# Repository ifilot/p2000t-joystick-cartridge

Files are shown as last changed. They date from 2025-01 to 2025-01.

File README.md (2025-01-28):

# P2000T Joystick Cartridge for SLOT2






This cartridge enables the use of Atari 2600-style joysticks with the P2000T by
emulating keyboard inputs. It uses an EEPROM and a few logic chips to translate
joystick button presses into keystrokes, seamlessly integrating with the
P2000T's keyboard polling process.

> [!TIP]
> Download a copy of the EEPROM binary [via this link](https://github.com/ifilot/p2000t-joystick-cartridge/releases/download/nightly/joystick_eeprom.bin).

## PCB

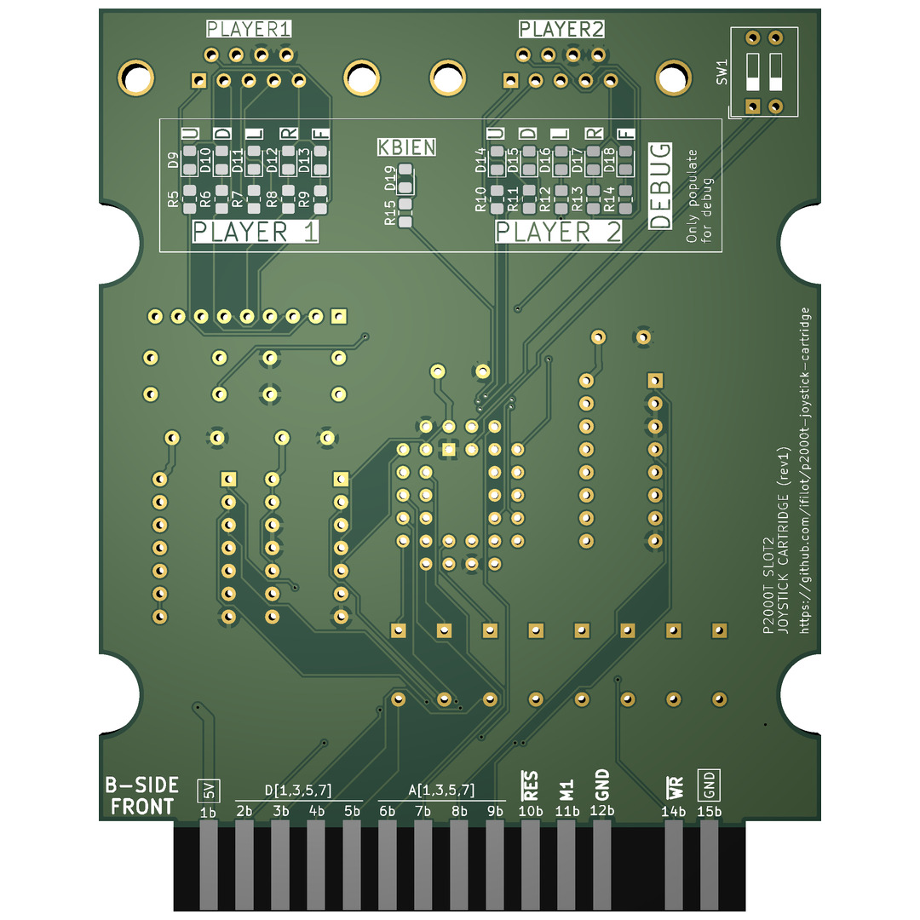
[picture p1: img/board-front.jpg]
PCB-front


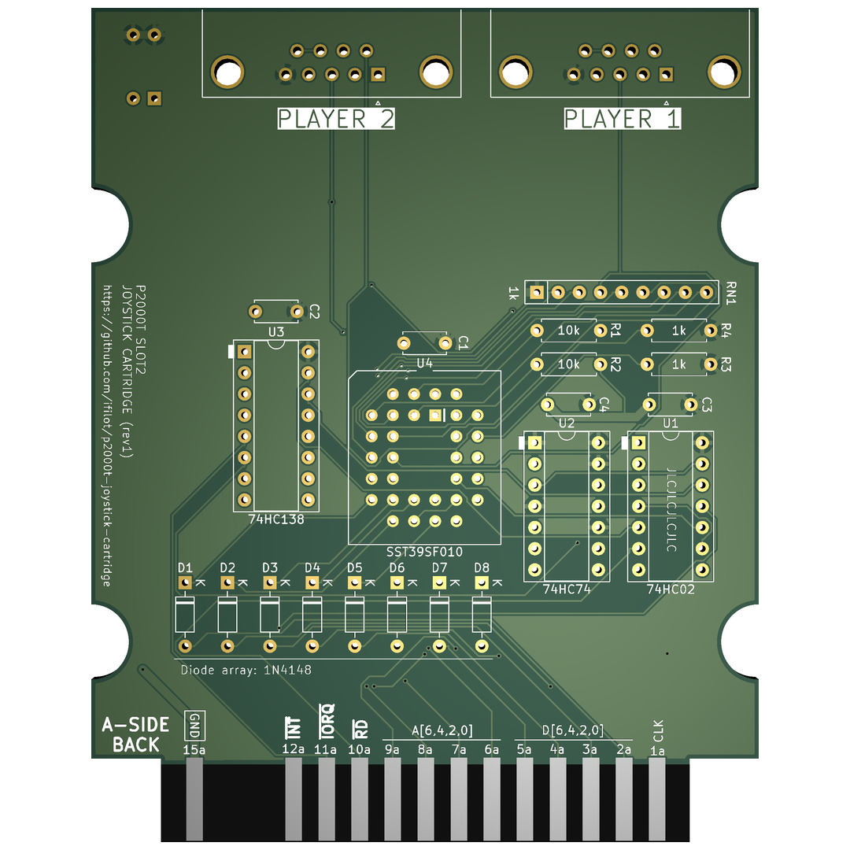
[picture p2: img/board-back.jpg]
PCB-back


## Working

The P2000T features a matrix keyboard design, where each key is positioned at the intersection of a specific row and column. The rows are connected to the address pins, while the columns are connected to the data pins. The keyboard matrix consists of 10 rows and 8 columns.

## Keyboard Polling Process

To poll the keyboard, the P2000T employs a two-step process:

1. **Initialize Rows**: The P2000T writes a `1` to the `BIT6` position of I/O
   port `0x10`, which ties all rows to ground (GND).
2. **Detect Key Presses**: The P2000T then reads from I/O port `0x00`. If at
   least one key is pressed, the read value will differ from `0xFF`.

If a key press is detected, the P2000T proceeds with an additional step:

3. **Detect specific key**: Each row is sequentially pulled down by reading from
   I/O ports `0x00` to `0x0A`. A zero-bit received during any of these read
   operations indicates the presence of a key press. The corresponding key is
   mapped to a specific keystroke based on its position in the matrix.

The described process is emulated using a single EEPROM and a few logic chips.
The EEPROM’s address pins are connected to both the joystick buttons and the
lower address bus used by the P2000T during the keyboard polling process. To
detect the polling of the lines, a 74HC138 decoder is used. This decoder latches
the D6 pin to capture the first phase of the keyboard polling process. During
this phase, if any joystick button is pressed, the EEPROM generates the same
output as if a key on the keyboard had been pressed. In the second phase, the
EEPROM continues the emulation process. However, it now produces the output
precisely when the corresponding row in the keyboard matrix is pulled low.

The use of an EEPROM makes this process fully programmable, allowing the user to
create any desired joystick-to-keyboard mapping. With 10 joystick buttons (5 per
joystick across 2 ports), only 32 KiB of EEPROM memory is required to store the
mappings. Since even the smallest SST39SF0x0-type EEPROM has a capacity of 128
KiB, a single chip can accommodate up to four different joystick/keyboard
mappings. To enable users to select their preferred mapping, a DIP switch is
included, allowing easy switching between the stored configurations.

### Schematic

[Download schematic](pcb/p2000t-joystick-slot2-eeprom/p2000t-joystick-slot2-eeprom.pdf)
PCB schematic

## Programming the EEPROM

To generate the data for the EEPROM, you can use [this
script](scripts/eeprom.py). The data can be written to the EEPROM using, for
example, [this hardware solution](https://github.com/ifilot/pico-sst39sf0x0-programmer).

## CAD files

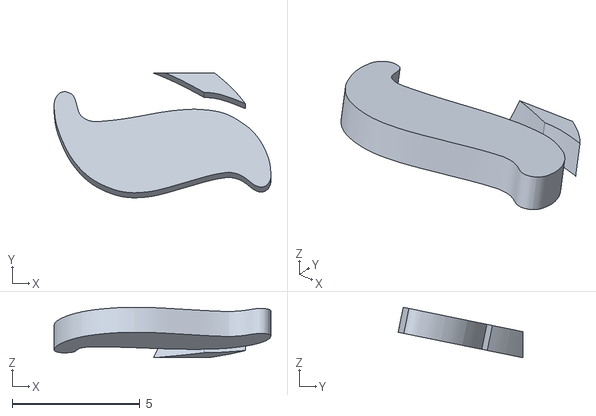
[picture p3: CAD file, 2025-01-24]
case/p2000t-joystick-cartridge-top-label.stl
8.51 x 4.90 x 1.98

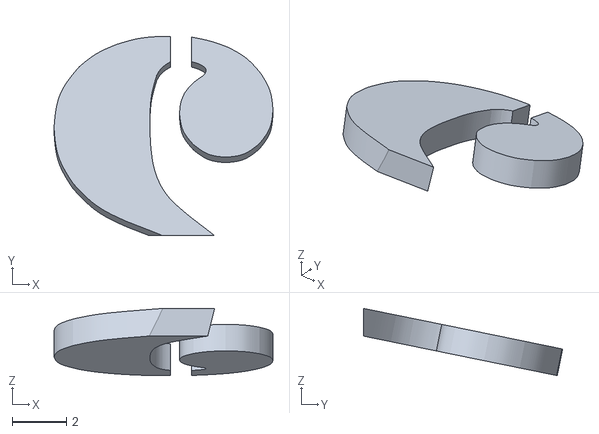
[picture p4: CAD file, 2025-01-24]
case/p2000t-joystick-cartridge-bottom-label.stl
8.08 x 7.35 x 2.48

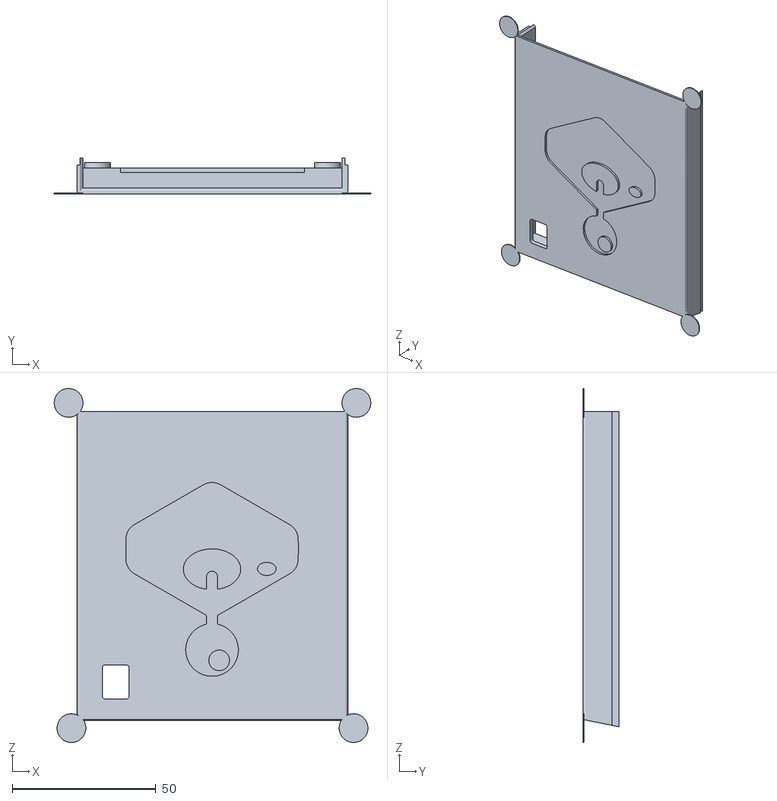
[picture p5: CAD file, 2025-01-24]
case/p2000t-joystick-cartridge-top.stl
110.0 x 12.5 x 123.0

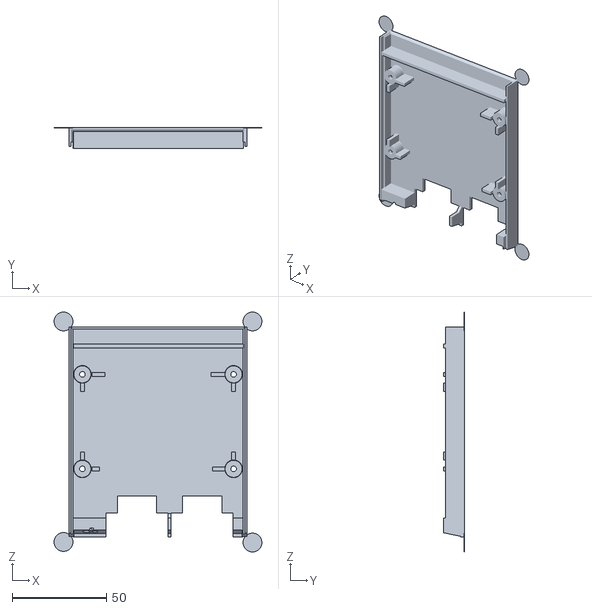
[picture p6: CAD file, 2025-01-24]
case/p2000t-joystick-cartridge-bottom.stl
110.0 x 11.0 x 127.0

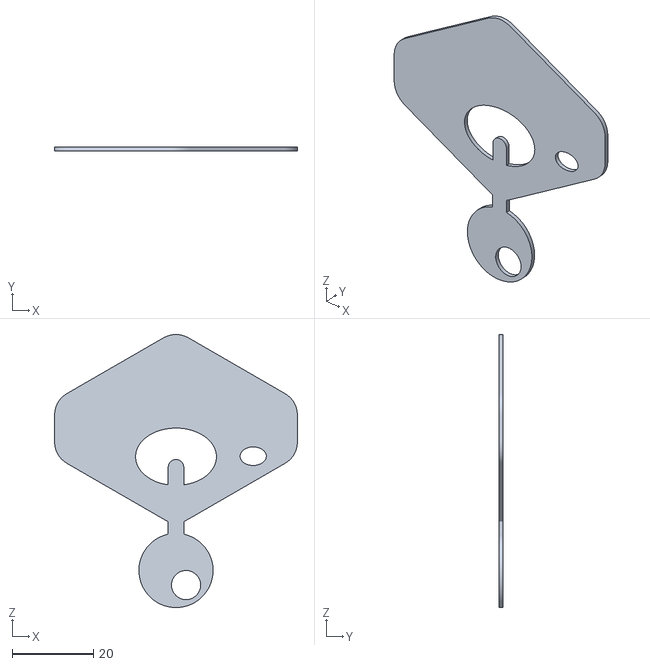
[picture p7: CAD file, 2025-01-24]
case/p2000t-joystick-cartridge-top-icon.stl
59.9 x 1.00 x 67.3

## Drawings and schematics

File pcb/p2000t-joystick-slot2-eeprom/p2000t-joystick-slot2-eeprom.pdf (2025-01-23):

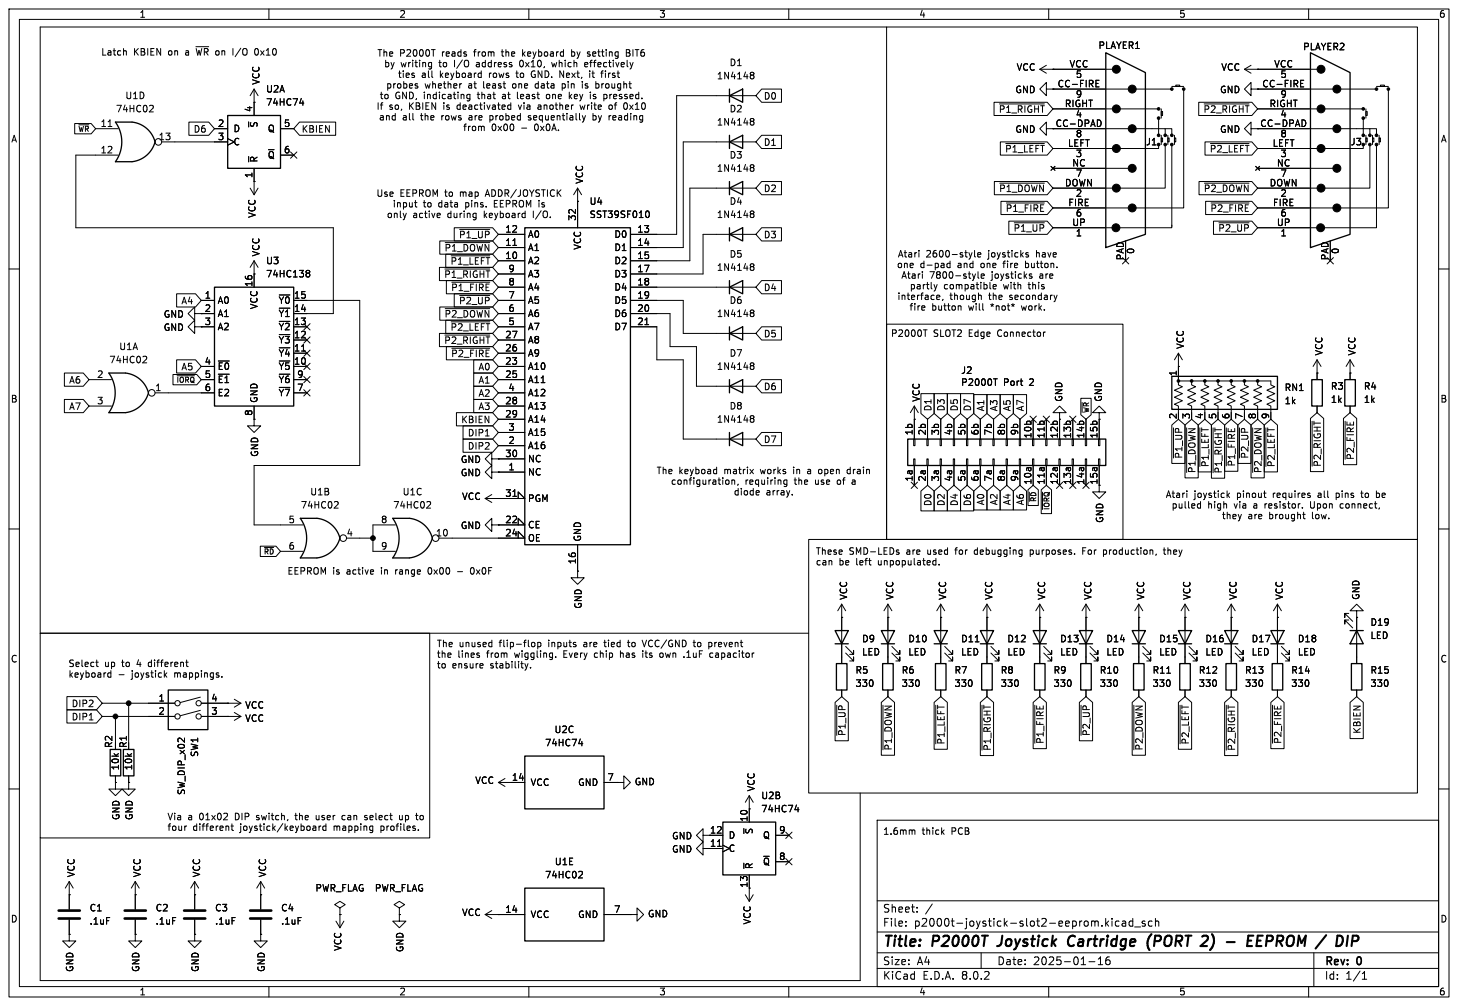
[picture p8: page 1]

input to data pins. EEPROM is only active during keyboard I/O. The P2000T reads from the keyboard by setting BIT6
by writing to I/O address 0x10, which effectively
ties all keyboard rows to GND. Next, it first probes whether at least one data pin is brought

~{P1_RIGHT} EEPROM is active in range 0x00 - 0x0F

8 ~{Y6}9 GND GND GND VCC

File: p2000t-joystick-slot2-eeprom.kicad_sch Sheet: /
Id: 1/1 Title: P2000T Joystick Cartridge (PORT 2) - EEPROM / DIP

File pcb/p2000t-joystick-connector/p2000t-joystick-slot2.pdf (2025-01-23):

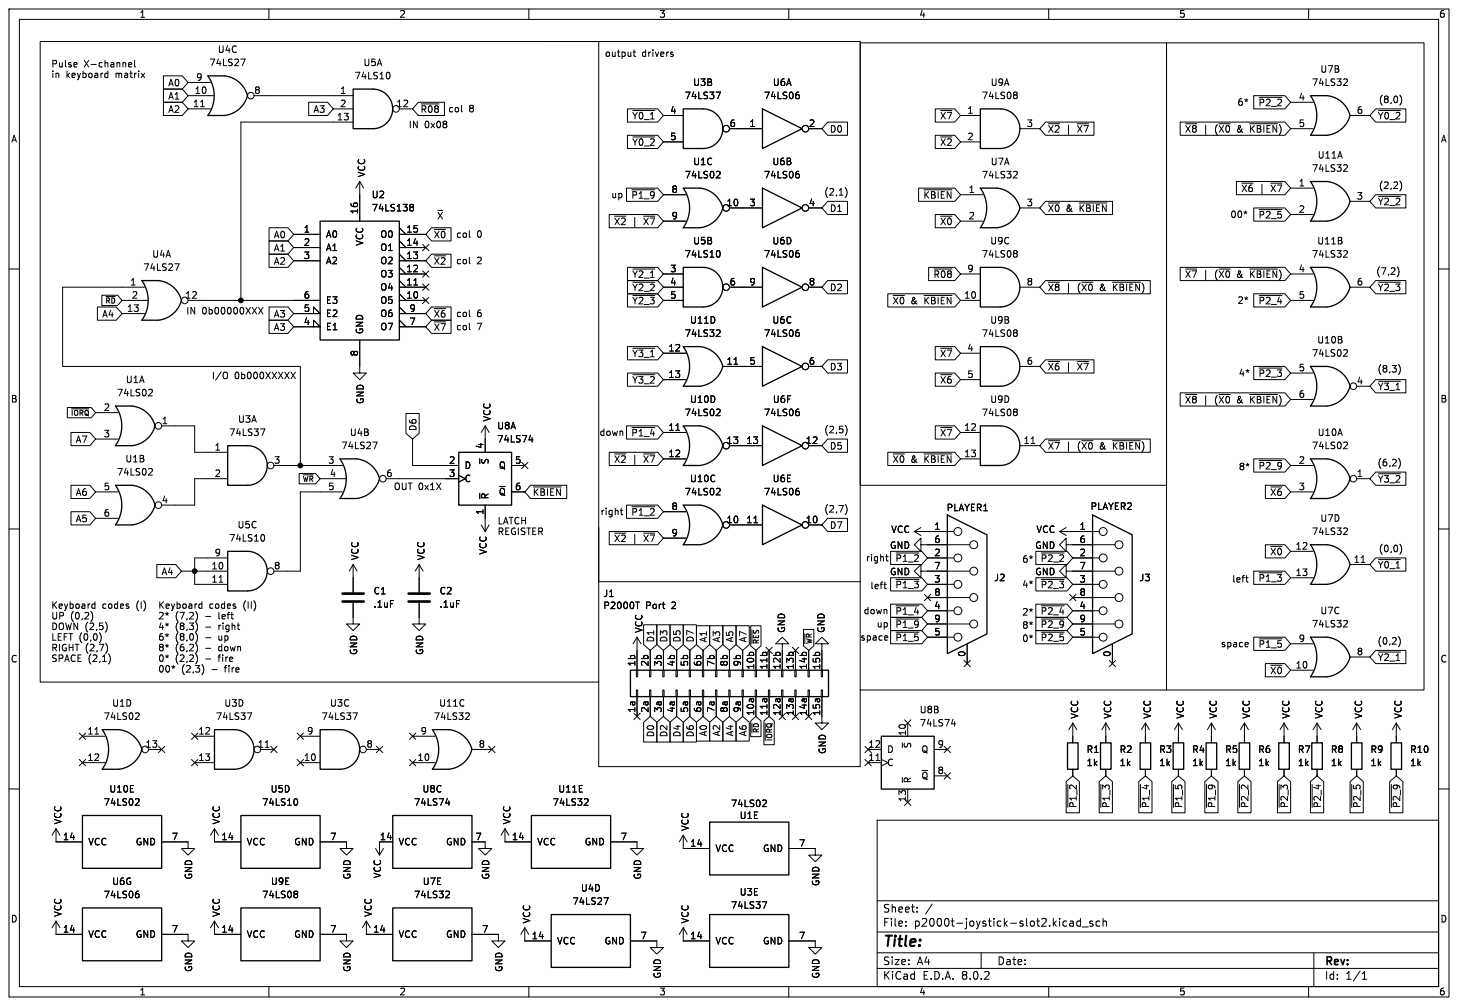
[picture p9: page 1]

Keyboard codes (I) UP (0,2) DOWN (2,5) LEFT (0,0) RIGHT (2,7) SPACE (2,1)

Keyboard codes (II) 2* (7,2) - left 4* (8,3) - right 6* (8,0) - up

Id: 1/1 Title: File: p2000t-joystick-slot2.kicad_sch Sheet: /

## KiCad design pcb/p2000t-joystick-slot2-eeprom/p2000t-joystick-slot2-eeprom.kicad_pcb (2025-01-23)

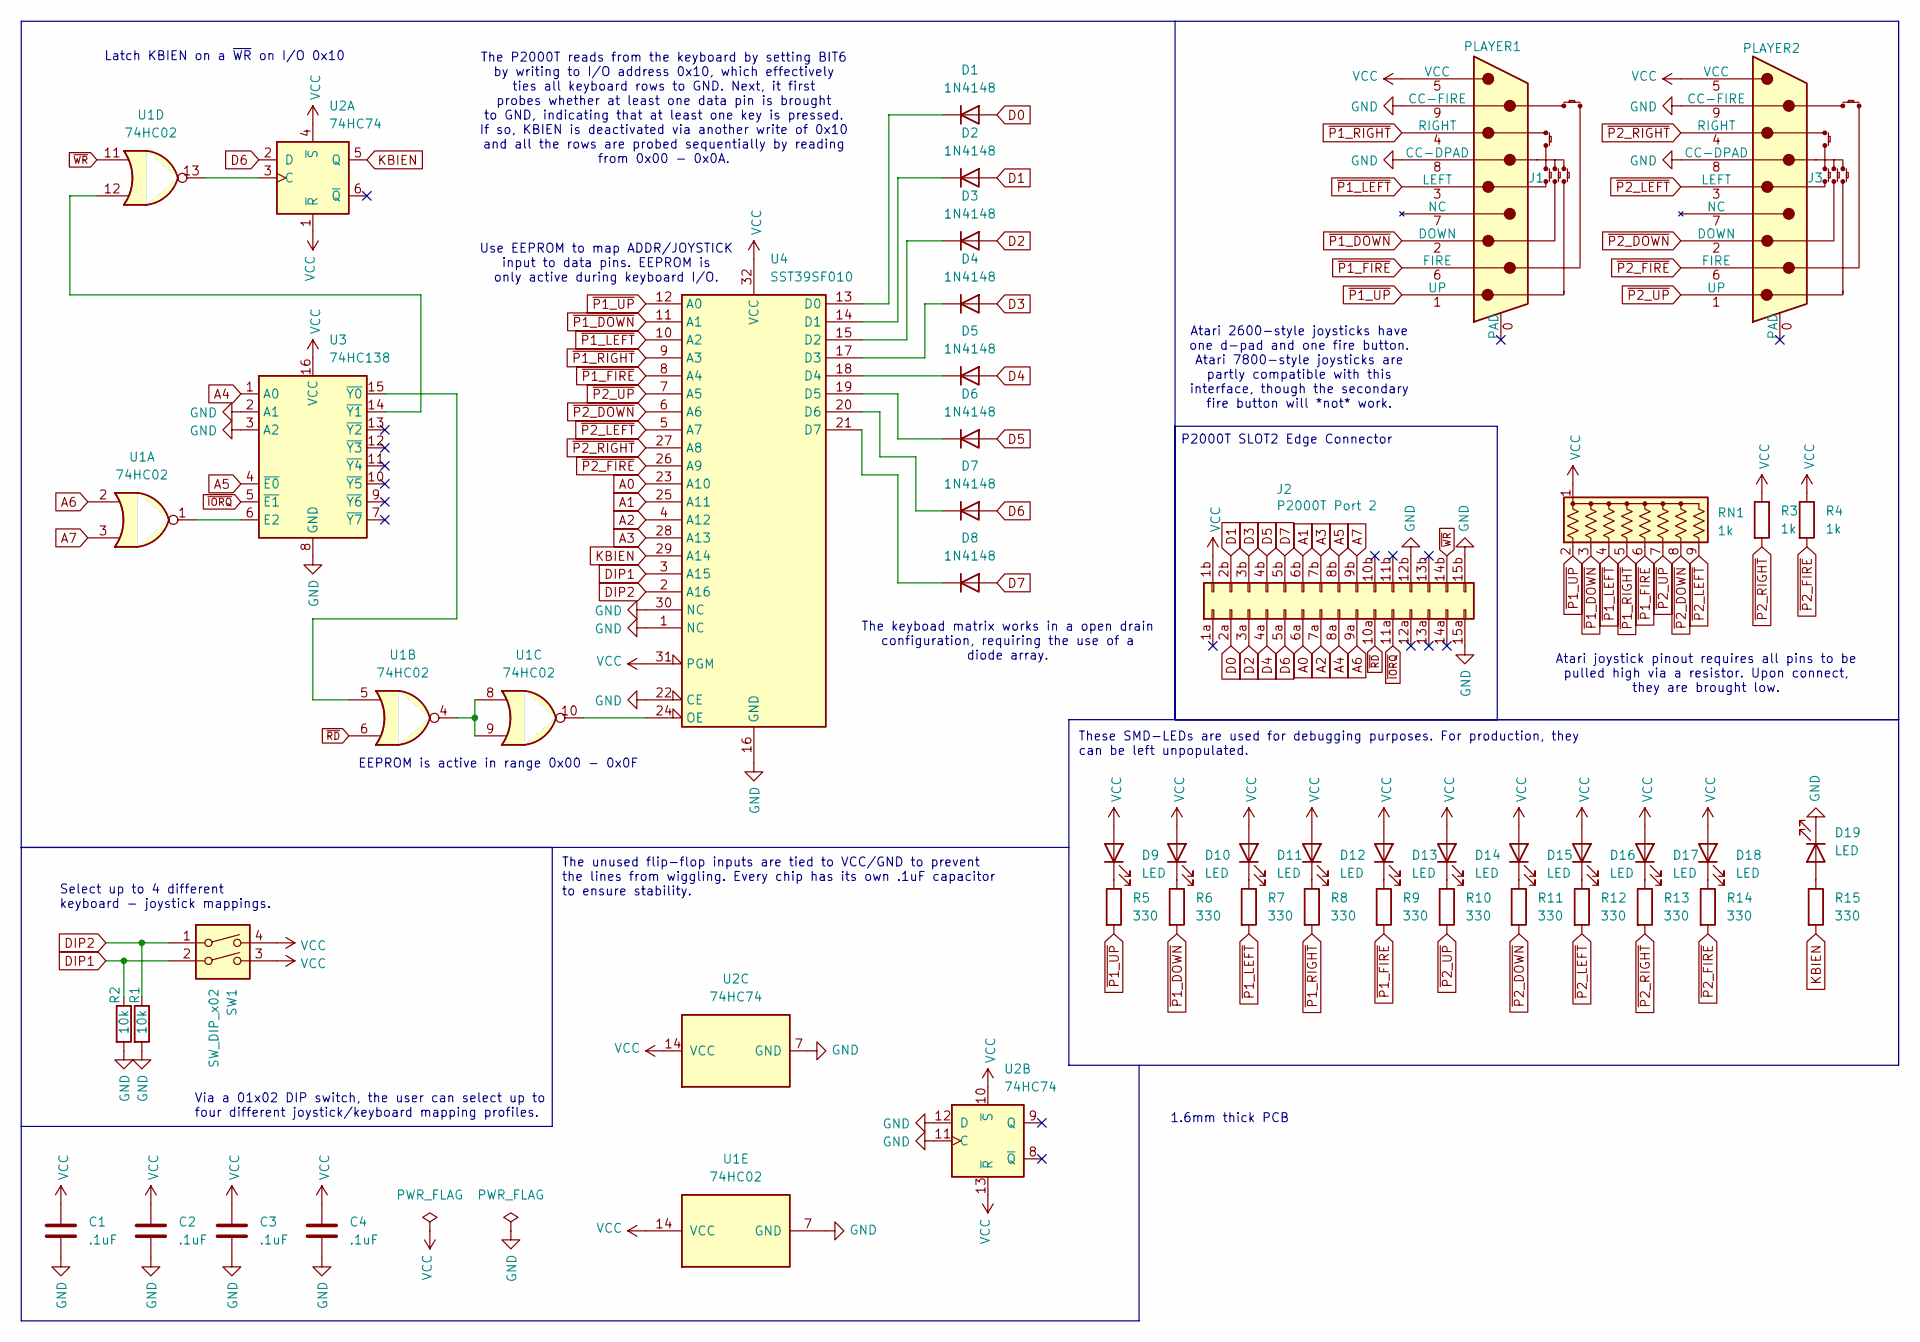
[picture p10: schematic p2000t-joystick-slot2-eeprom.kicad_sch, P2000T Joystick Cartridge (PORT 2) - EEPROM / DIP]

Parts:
C1, C2, C3, C4: .1uF; C_Disc_D5.0mm_W2.5mm_P5.00mm
D1, D2, D3, D4, D5, D6, D7, D8: 1N4148; D_DO-35_SOD27_P7.62mm_Horizontal
D9, D10, D11, D12, D13, D14, D15, D16, D17, D18, D19: LED; LED_0805_2012Metric_Pad1.15x1.40mm_HandSolder
J1: PLAYER1; DSUB-9_Male_Horizontal_P2.77x2.84mm_EdgePinOffset4.94mm_Hou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
J2: P2000T Port 2; p2000t_cartridge_edge
J3: PLAYER2; DSUB-9_Male_Horizontal_P2.77x2.84mm_EdgePinOffset4.94mm_Hou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
R1, R2: 10k; R_Axial_DIN0207_L6.3mm_D2.5mm_P7.62mm_Horizontal
R3, R4: 1k; R_Axial_DIN0207_L6.3mm_D2.5mm_P7.62mm_Horizontal
R5, R6, R7, R8, R9, R10, R11, R12, R13, R14, R15: 330; R_0805_2012Metric_Pad1.20x1.40mm_HandSolder
RN1: 1k; R_Array_SIP9
SW1: SW_DIP_x02; SW_DIP_SPSTx02_Slide_9.78x7.26mm_W7.62mm_P2.54mm
U1: 74HC02; DIP-14_W7.62mm_Socket
U2: 74HC74; DIP-14_W7.62mm_Socket
U3: 74HC138; DIP-16_W7.62mm_Socket
U4: SST39SF010; PLCC-32_THT-Socket

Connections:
A0: J2.6a, U4.23 (A10)
A1: J2.6b, U4.25 (A11)
A2: J2.7a, U4.4 (A12)
A3: J2.7b, U4.28 (A13)
A4: J2.8a, U3.1 (A0)
A5: J2.8b, U3.4 (~E0)
A6: J2.9a, U1.2
A7: J2.9b, U1.3
D0: D1.2 (A), J2.2a
D1: D2.2 (A), J2.2b
D2: D3.2 (A), J2.3a
D3: D4.2 (A), J2.3b
D4: D5.2 (A), J2.4a
D5: D6.2 (A), J2.4b
D6: D7.2 (A), J2.5a, U2.2 (D)
D7: D8.2 (A), J2.5b
DIP1: R2.1, SW1.2, U4.3 (A15)
DIP2: R1.1, SW1.1, U4.2 (A16)
GND: C1.2, C2.2, C3.2, C4.2, D19.1 (K), J1.8 (CC-DPAD), J1.9 (CC-FIRE), J2.12b, J2.15a, J2.15b, J3.8 (CC-DPAD), J3.9 (CC-FIRE), R1.2, R2.2, U1.7 (GND), U2.7 (GND), U2.11 (C), U2.12 (D), U3.2 (A1), U3.3 (A2), U3.8 (GND), U4.1 (NC), U4.16 (GND), U4.22 (CE), U4.30 (NC)
KBIEN: R15.2, U2.5 (Q), U4.29 (A14)
unnamed: D1.1 (K), U4.13 (D0)
unnamed: D2.1 (K), U4.14 (D1)
unnamed: D3.1 (K), U4.15 (D2)
unnamed: D4.1 (K), U4.17 (D3)
unnamed: D5.1 (K), U4.18 (D4)
unnamed: D6.1 (K), U4.19 (D5)
unnamed: D7.1 (K), U4.20 (D6)
unnamed: D8.1 (K), U4.21 (D7)
unnamed: D9.1 (K), R5.1
unnamed: D10.1 (K), R6.1
unnamed: D11.1 (K), R7.1
unnamed: D12.1 (K), R8.1
unnamed: D13.1 (K), R9.1
unnamed: D14.1 (K), R10.1
unnamed: D15.1 (K), R11.1
unnamed: D16.1 (K), R12.1
unnamed: D17.1 (K), R13.1
unnamed: D18.1 (K), R14.1
unnamed: D19.2 (A), R15.1
unnamed: U1.4, U1.8, U1.9
unnamed: U1.13, U2.3 (C)
unnamed: U1.1, U3.6 (E2)
unnamed: U1.5, U3.15 (~Y0)
unnamed: U1.12, U3.14 (~Y1)
unnamed: U1.10, U4.24 (OE)
VCC: C1.1, C2.1, C3.1, C4.1, D9.2 (A), D10.2 (A), D11.2 (A), D12.2 (A), D13.2 (A), D14.2 (A), D15.2 (A), D16.2 (A), D17.2 (A), D18.2 (A), J1.5 (VCC), J2.1b, J3.5 (VCC), R3.1, R4.1, RN1.1 (common), SW1.3, SW1.4, U1.14 (VCC), U2.1 (~R), U2.4 (~S), U2.10 (~S), U2.13 (~R), U2.14 (VCC), U3.16 (VCC), U4.31 (PGM), U4.32 (VCC)
~IORQ: J2.11a, U3.5 (~E1)
~P1_DOWN: J1.2 (DOWN), R6.2, RN1.3 (R2), U4.11 (A1)
~P1_FIRE: J1.6 (FIRE), R9.2, RN1.6 (R5), U4.8 (A4)
~P1_LEFT: J1.3 (LEFT), R7.2, RN1.4 (R3), U4.10 (A2)
~P1_RIGHT: J1.4 (RIGHT), R8.2, RN1.5 (R4), U4.9 (A3)
~P1_UP: J1.1 (UP), R5.2, RN1.2 (R1), U4.12 (A0)
~P2_DOWN: J3.2 (DOWN), R11.2, RN1.8 (R7), U4.6 (A6)
~P2_FIRE: J3.6 (FIRE), R4.2, R14.2, U4.26 (A9)
~P2_LEFT: J3.3 (LEFT), R12.2, RN1.9 (R8), U4.5 (A7)
~P2_RIGHT: J3.4 (RIGHT), R3.2, R13.2, U4.27 (A8)
~P2_UP: J3.1 (UP), R10.2, RN1.7 (R6), U4.7 (A5)
~RD: J2.10a, U1.6
~WR: J2.14b, U1.11

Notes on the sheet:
Latch KBIEN on a ~{WR} on I/O 0x10
Atari joystick pinout requires all pins to be pulled high via a resistor. Upon connect, they are brought low.
The keyboad matrix works in a open drain configuration, requiring the use of a diode array.
Select up to 4 different keyboard - joystick mappings.
Use EEPROM to map ADDR/JOYSTICK input to data pins. EEPROM is only active during keyboard I/O.
EEPROM is active in range 0x00 - 0x0F
P2000T SLOT2 Edge Connector
The P2000T reads from the keyboard by setting BIT6 by writing to I/O address 0x10, which effectively ties all keyboard rows to GND. Next, it first probes whether at least one data pin is brought to GND, indicating that at least one key is pressed. If so, KBIEN is deactivated via another write of 0x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
These SMD-LEDs are used for debugging purposes. For production, they can be left unpopulated.
The unused flip-flop inputs are tied to VCC/GND to prevent the lines from wiggling. Every chip has its own .1uF capacitor to ensure stability.
1.6mm thick PCB
Atari 2600-style joysticks have one d-pad and one fire button. Atari 7800-style joysticks are partly compatible with this interface, though the secondary fire button will *not* work.
Via a 01x02 DIP switch, the user can select up to four different joystick/keyboard mapping profiles.

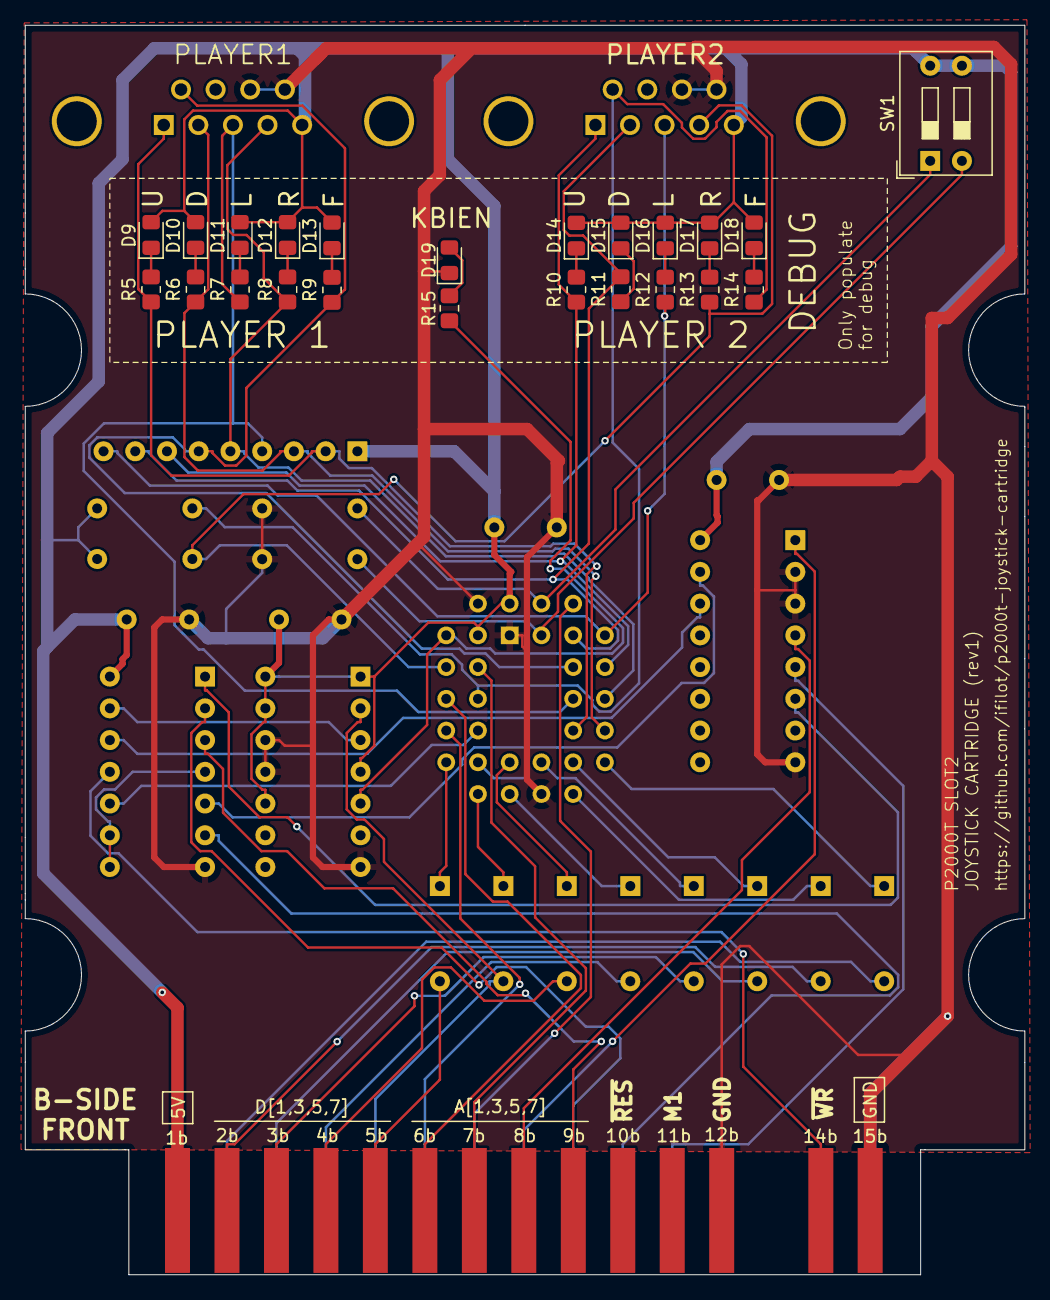
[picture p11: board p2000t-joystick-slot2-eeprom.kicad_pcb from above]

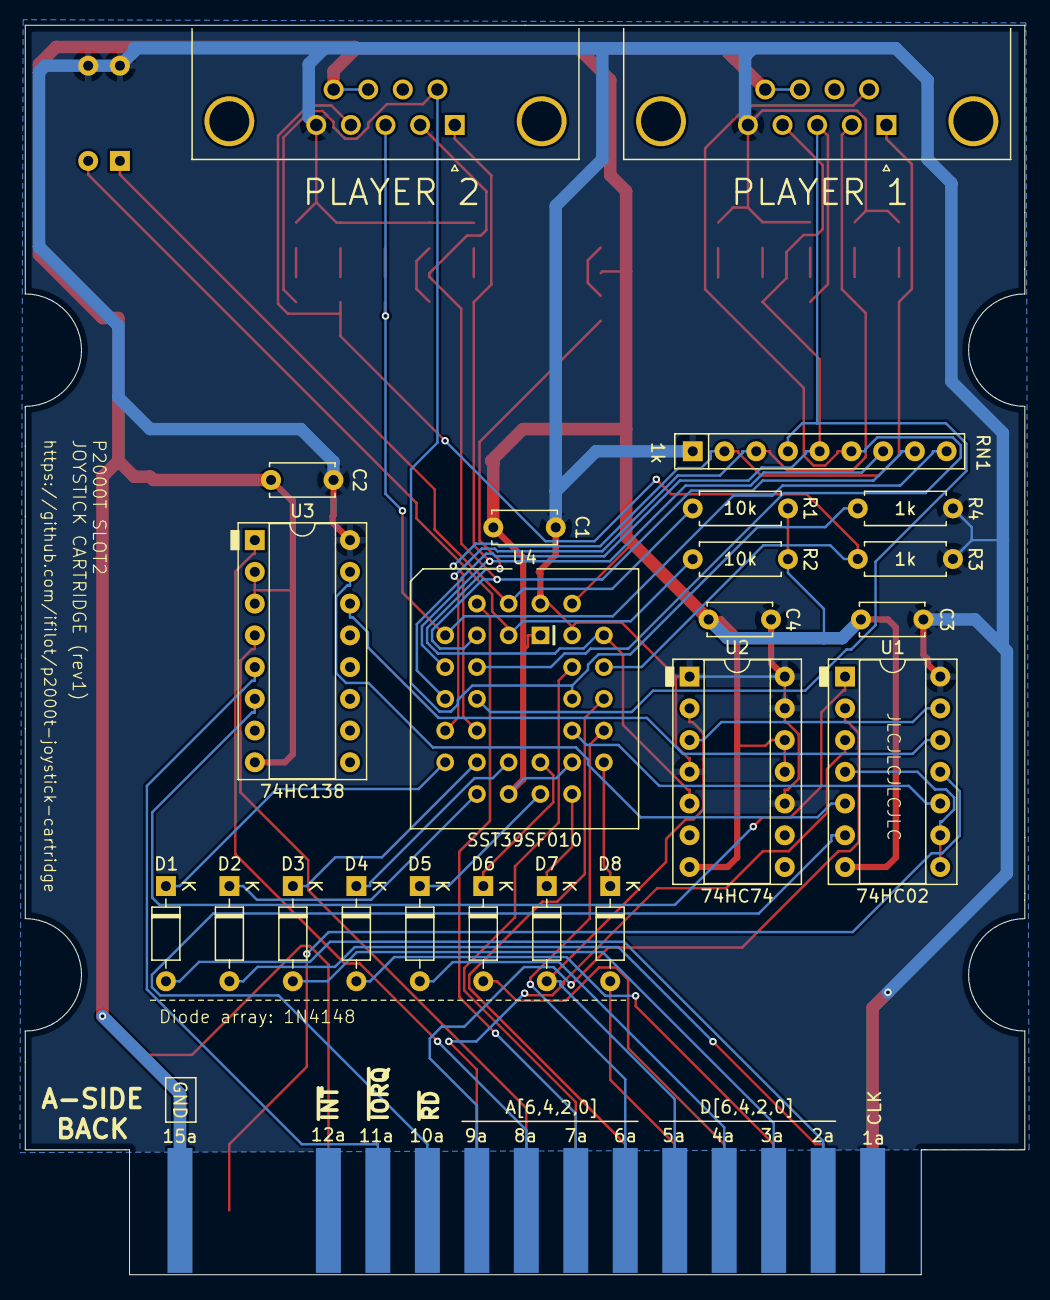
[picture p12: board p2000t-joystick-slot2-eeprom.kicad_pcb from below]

Board: 2 copper layers, 80.0 x 100.0 mm, 47 parts (24 on the bottom side), 59 nets.

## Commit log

2025-01-23 Revising joystick case
    [p2000t-joystick-cartridge-bottom.stl, p2000t-joystick-cartridge-eeprom-prototype-bottom.stl, p2000t-joystick-cartridge-eeprom-prototype-top.stl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]
2025-01-23 Revising cases
    [p2000t-joystick-cartridge-bottom.stl, p2000t-joystick-cartridge-top.stl]
2025-01-24 Revising case
    [p2000t-joystick-cartridge-bottom-label.stl, p2000t-joystick-cartridge-bottom.stl, p2000t-joystick-cartridge-top-icon.stl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]

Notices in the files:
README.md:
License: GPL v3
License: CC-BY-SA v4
